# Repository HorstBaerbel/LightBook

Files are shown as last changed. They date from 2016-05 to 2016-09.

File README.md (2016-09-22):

This repository contains two similar projects: LightBook and GIFBook:  

LightBook
========
LightBook is a project that uses an ESP8266-201 module, a SD card and a WS2812 RGB LED strip (arranged as a 8*8 array) as a WiFi-enabled interactive canvas. The ESP8266 WiFi access point serves a minimalistic web page that can be used to "paint" on the LED display. The whole electronics are packaged in an old book to be put into a bookshelf.  
The code is written for the ESP8266 Arduino IDE and uses FastLED for driving the LED strip. WebSockets are used to exchange binary messages between JavaScript and the ESP module.  
The [Fritzing](http://fritzing.org/) circuit layout can be found in [LightBook_SD.fzz](LightBook_SD.fzz) and the necessary Arduino source code in [LightBook/LightBook.ino](LightBook/LightBook.ino).  
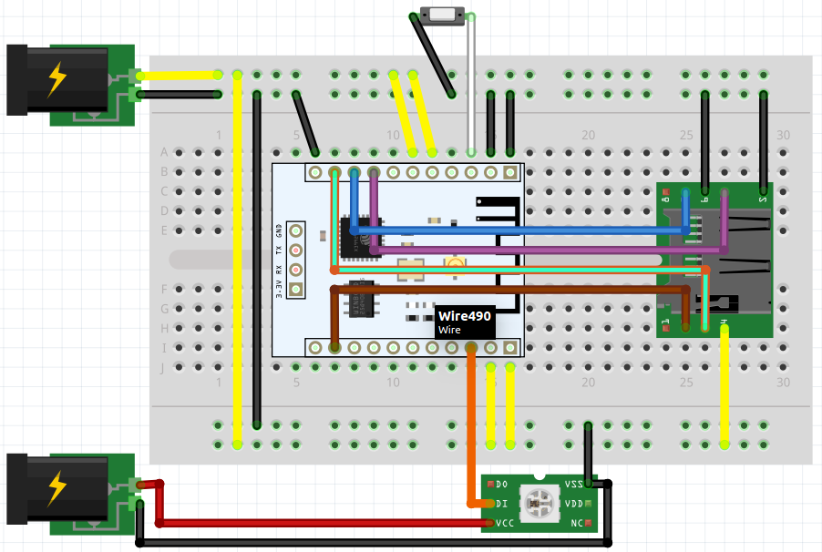
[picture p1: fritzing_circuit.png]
Fritzing circuit layout
  
You need 3.3V for the ESP8266 and 5V for the LED strip (thus the two power connectors). I generated the 3.3V with a step-down converter from the 5V line.  
Note that theres NO resistor in the WS2812s data line! The usual recommendation is to insert a ~220&#8486; resistor into the data line to prevent strips from dying, but for me this caused flickering issues due to the 3.3V signals from the ESP and does not seem to be necessary...  
Also note that only GPIOs 2 (TX1), 4 (SDA), 5 (SCL), 12 (MISO), 13 (MOSI), 14 (SCK) can be used for LED strips. GPIOs 6-11 are needed for reading/writing the attached flash chip. In theory GPIO 0, 15, 16 could work, but 0 is needed for flashing, 15 needs to be connected to GND and 16 is connected to Reset to wake the ESP from deep sleep mode. Read more about those pins here: http://www.instructables.com/id/ESP8266-Using-GPIO0-GPIO2-as-inputs/  
This circuit uses GPIO 2 and 12-14 for the SD card interface and GPIO 4 for the WS2812 strip. This leaves you with only GPIO 5 (SCL) left free for other connections...  
Some general ESP8266 GPIO info is here: http://www.esp8266.com/wiki/doku.php?id=esp8266_gpio_pin_allocations and a ESP-201 pinout is here: http://adlerweb.deviantart.com/art/ESP8266-ESP-201-Module-Pinout-Diagram-Cheat-Sheet-575951137  
The web page served look something like this and allows for simple pixel-painting on the display:  
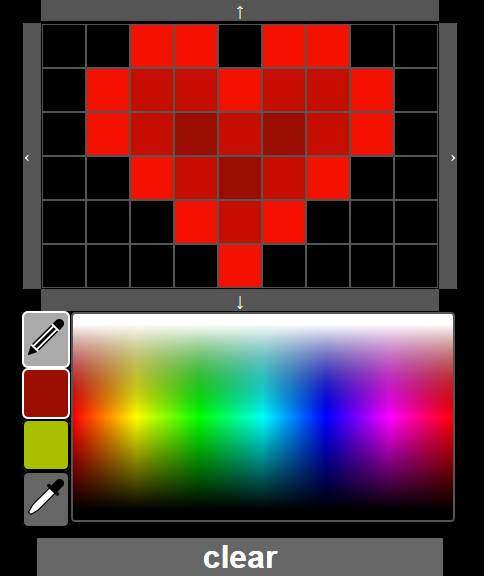
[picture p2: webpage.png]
LightBook web page served
  

GIFBook
========
GIFBook is a project that uses an ESP8266-201 module, a SD card and a WS2812 RGB LED strip (arranged as a 8*8 array) as a WiFi-enabled GIF player. You can toggle the GIF being played using a button.  
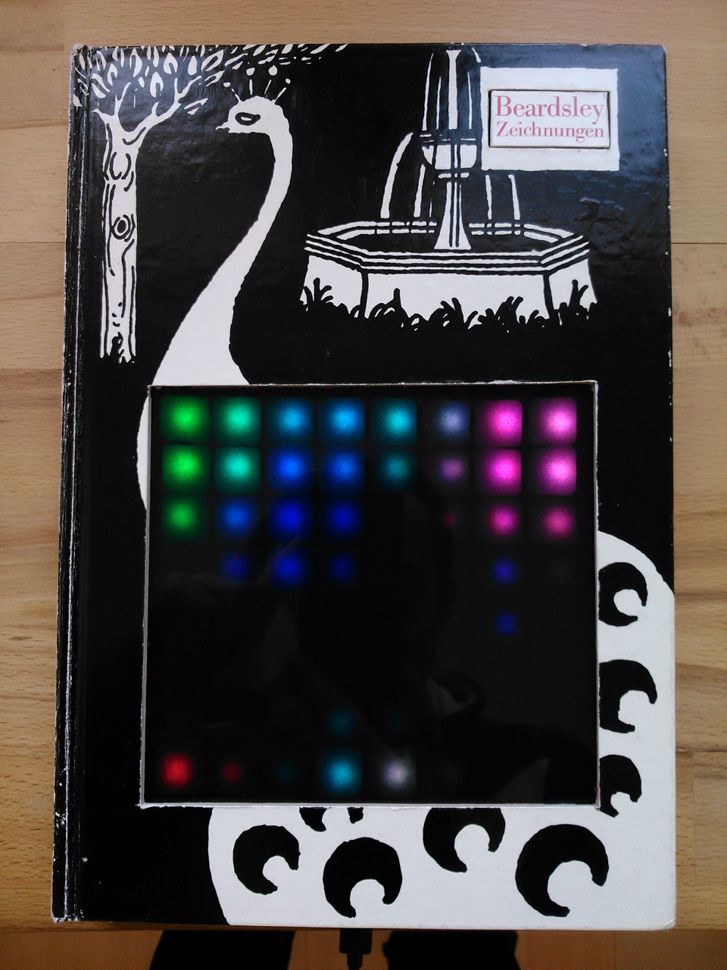
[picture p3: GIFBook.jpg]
GIFBook front
  
The code is written for the ESP8266 Arduino IDE and uses FastLED for driving the LED strip. WebSockets are used to exchange binary messages between JavaScript and the ESP module.  
The [Fritzing](http://fritzing.org/) circuit layout can be found in [LightBook_SD.fzz](LightBook_SD.fzz) and the necessary Arduino source code in [GIFBook/GIFBook.ino](GIFBook/GIFBook.ino).  
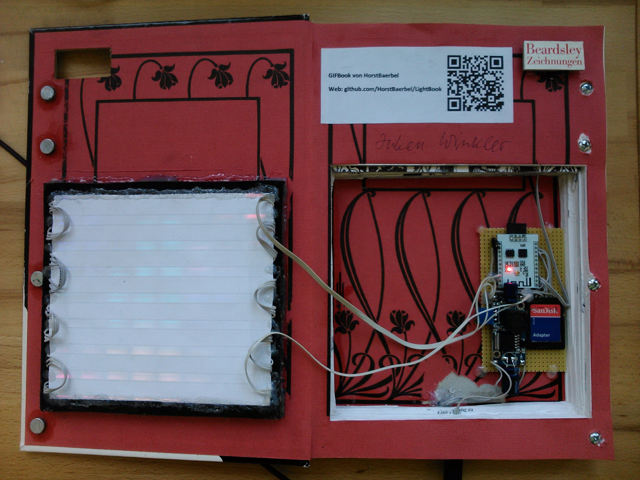
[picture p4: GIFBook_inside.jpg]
GIFBook inside
  
GIFbook plays 8x8 (and ONLY 8x8) GIFs from the /gifs folder on the SD card. It start with the first GIF (which is btw the GIF file copied to SD card first) and you can skip to the next GIF by short-pressing the button connnected to GPIO5.  

License
========
[BSD-2-Clause](http://opensource.org/licenses/BSD-2-Clause), see [LICENSE.md](LICENSE.md).  
AnimatedGIFs uses the [MIT license](https://opensource.org/licenses/MIT), see [LICENSE.txt](AnimatedGIFs/LICENSE.txt).  
I hope those are compatible...

Compiling
========
Make sure you have a recent Arduino IDE version (1.6.9+) and [support for the ESP8266](https://github.com/esp8266/Arduino). You may also need the most recent [FastLED](https://github.com/FastLED/FastLED) version. The content of the data folder should go to your FAT32-formatted SD card.  
To compile GIFBook you additionally need the wonderful [AnimatedGIFs](https://github.com/pixelmatix/AnimatedGIFs) project by [pixelmatix](https://github.com/pixelmatix) that I cloned into the AnimatedGIFs directory as a submodule. Copy the whole AnimatedGIFs folder to your Arduino library directory.

Usage
========
For LightBook, power up the circuit, connect to the AP, browse to [http://lightbook](http://lightbook) and go paint something nice :)  
For GIFBook, just power it on and push the button to show the next GIF.

I found a bug or have a suggestion
========
The best way to report a bug or suggest something is to post an issue on GitHub. Try to make it simple, but descriptive and add ALL the information needed to REPRODUCE the bug. **"Does not work" is not enough!** If you can not compile, please state your system, compiler version, etc! You can also contact me via email if you want to.

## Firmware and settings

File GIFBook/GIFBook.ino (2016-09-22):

// GIFBook sketch
// Version: v1, 21.07.2016
// Author: Bim Overbohm (bim.overbohm@googlemail.com)

// define this to have debug messages printed to the serial port
//#define OUTPUT_TO_SERIAL
#ifdef OUTPUT_TO_SERIAL
    #define DEBUG_OUTPUT(x) x
#else
    #define DEBUG_OUTPUT(x)
#endif

//#define FASTLED_ALLOW_INTERRUPTS 0 // define this if you have issues with flickering
#define FASTLED_ESP8266_RAW_PIN_ORDER // to use regular ESP GPIO numbers like GPIO13
#include "FastLED.h"

#define LED_DATA_PIN 4
//#define LED_CLOCK_PIN 5
#define LEDS_WIDTH 8
#define LEDS_HEIGHT 8
#define NUM_LEDS LEDS_WIDTH * LEDS_HEIGHT
CRGB leds[NUM_LEDS];
int16_t ledIndex[LEDS_HEIGHT][LEDS_WIDTH];
bool colorChanged = false;

//-----------------------------------------------------------------------------

#include <SPI.h>
#include <SD.h>
// set up variables using the SD utility library functions:
#define SD_CARD_CS_PIN 2
bool sdCardAvailable = false;

//-----------------------------------------------------------------------------

#include <ESP8266WiFi.h>
#include <ESP8266WebServer.h>
#include <DNSServer.h>
#include <WebSocketsServer.h>

const char * AP_SSID = "LightBook";
// const char * AP_PASSWORD = "87654321";
IPAddress AP_IP(192, 168, 1, 1);

const uint8_t DNS_PORT = 53;
DNSServer dnsServer;

WebSocketsServer webSocket = WebSocketsServer(81);
const uint8_t webSocketResponseOk[] = { 1 };
const uint8_t webSocketResponseNOk[] = { 0 };

const uint8_t MESSAGE_GIF_SELECT = 'g';

ESP8266WebServer webServer(80);
const String gifDirectory = "/gifs";
File uploadFile;

//-----------------------------------------------------------------------------

#define BUTTON_PIN 5 // button to cycle GIFs

//button press durations in ms
#define RELEASE_DURATION 50
#define SHORT_PRESS_DURATION 50
#define LONG_PRESS_DURATION 4000

//button state variables.
uint8_t lastButtonPin = LOW;
int32_t lastButtonStart = 0;
uint8_t currentButtonState = 0; //0 = released, 1 = short pressed, 2 = long pressed
bool buttonWasPressedShort = false;
bool buttonWasPressedLong = false;

//-----------------------------------------------------------------------------

#include "GifDecoder.h"
GifDecoder<LEDS_WIDTH, LEDS_HEIGHT, 10> gifDecoder;
File gifFile;
String gifFileName = "";

//-----------------------------------------------------------------------------

void webSocketSendServerMessage(uint8_t num, const uint8_t * payload, size_t length)
{
    uint8_t * message = new uint8_t[sizeof(uint32_t) + length];
    *((uint32_t *)message) = 0;
    memcpy(&message[sizeof(uint32_t)], payload, length);
    webSocket.sendBIN(num, message, sizeof(uint32_t) + length);
    delete message;
}

void webSocketSendResponse(uint8_t num, uint32_t messageId, bool ok)
{
    uint8_t response[5];
    *((uint32_t *)response) = messageId;
    response[4] = (uint8_t)ok;
    webSocket.sendBIN(num, response, sizeof(response));
}

uint32_t webSocketMessageIdFromData(const uint8_t * payload, size_t length)
{
    if (payload != nullptr && length >= 4) {
        uint32_t id = *((const uint32_t *)payload);
        return id;
    }
    return 0;
}

void webSocketHandleMessage(uint8_t num, WStype_t type, uint8_t * payload, size_t length)
{
    DEBUG_OUTPUT(Serial.print("Message from client #");) DEBUG_OUTPUT(Serial.println(num);)
    //for (int i = 0; i < length; ++i) { DEBUG_OUTPUT(Serial.print(payload[i]);) DEBUG_OUTPUT(Serial.print(" ");) } DEBUG_OUTPUT(Serial.println();)
    // check the type of event
    switch(type)
    {
    case WStype_DISCONNECTED:
        DEBUG_OUTPUT(Serial.println("Websocket disonnected");)
        break;
    case WStype_CONNECTED:
        DEBUG_OUTPUT(Serial.println("Websocket connected");)
        break;
    case WStype_TEXT:
        // unknown message, send negative response
        DEBUG_OUTPUT(Serial.println("Unknown text message received");)
        webSocketSendResponse(num, 0, false);
        //webSocket.sendTXT(num, payload, length); // send to client
        //webSocket.broadcastTXT(payload, length); // send to all clients
        break;
    case WStype_BIN:
        // check if the packet contained data
        if (payload != nullptr && length > 4)
        {
            const uint32_t messageId = webSocketMessageIdFromData(payload, length);
            const char messageType = (char)payload[4];
            const uint8_t * messageData = (const uint8_t *)&payload[5];
            DEBUG_OUTPUT(Serial.print("Binary message id: ");) DEBUG_OUTPUT(Serial.print(messageId);) DEBUG_OUTPUT(Serial.print(" type: ");) DEBUG_OUTPUT(Serial.print(messageType);) DEBUG_OUTPUT(Serial.println(" received");)
            // check if this is a color for a specific led. format is ID, 'g', file name.gif
            if (messageType == MESSAGE_GIF_SELECT && length >= 6)
            {
                webSocketSendResponse(num, messageId, true);
            }
            else
            {
                // unknown message, send negative response
                webSocketSendResponse(num, messageId, false);
            }
        }
        break;
    }
}

//-----------------------------------------------------------------------------

void returnOk()
{
  webServer.send(200, "text/plain", "");
}

void returnFail(String msg)
{
  webServer.send(500, "text/plain", msg + "\r\n");
}

void returnDoesNotExist(String msg)
{
  webServer.send(404, "text/plain", msg + "\r\n");
}

String getContentType(String filename){
    if (webServer.hasArg("download")) return "application/octet-stream";
    else if (filename.endsWith(".htm")) return "text/html";
    else if (filename.endsWith(".html")) return "text/html";
    else if (filename.endsWith(".css")) return "text/css";
    else if (filename.endsWith(".js")) return "application/javascript";
    else if (filename.endsWith(".png")) return "image/png";
    else if (filename.endsWith(".gif")) return "image/gif";
    else if (filename.endsWith(".jpg")) return "image/jpeg";
    else if (filename.endsWith(".ico")) return "image/x-icon";
    else if (filename.endsWith(".xml")) return "text/xml";
    else if (filename.endsWith(".pdf")) return "application/x-pdf";
    else if (filename.endsWith(".zip")) return "application/x-zip";
    else if (filename.endsWith(".gz")) return "application/x-gzip";
    return "text/plain";
}

bool loadFileFromSDCard(String path)
{
    if (!sdCardAvailable) {
        return false;
    }
    String dataType = getContentType(path);
    // try opening file
    DEBUG_OUTPUT(Serial.print("Opening: ");) DEBUG_OUTPUT(Serial.println(path);)
    File dataFile = SD.open(path.c_str());
    // check if directory and add index.htm to it
    if (dataFile.isDirectory()) {
        path += "/index.htm";
        dataType = "text/html";
        dataFile = SD.open(path.c_str());
    }
    // check if opened
    if (!dataFile) {
        DEBUG_OUTPUT(Serial.println("Failed to open file.");)
        return false;
    }
    // send data to client
    //if (server.hasArg("download")) dataType = "application/octet-stream";
    if (webServer.streamFile(dataFile, dataType) != dataFile.size()) {
        DEBUG_OUTPUT(Serial.println("Sent less data than expected!");)
    }
    dataFile.close();
    return true;
}

void handleClientRequest()
{
    DEBUG_OUTPUT(Serial.print("Page request: ");) DEBUG_OUTPUT(Serial.println(webServer.uri());)
    if (!loadFileFromSDCard(webServer.uri())) {
        returnDoesNotExist("Page " + webServer.uri() + " does not exist or no SD card inserted!");
    }
    returnOk();
}

void handleFileUpload()
{
    // check URI for image directory
    if (webServer.uri() != gifDirectory) {
        returnFail("Bad path");
        return;
    }
    // check if the upload path contains the image directory
    HTTPUpload & upload = webServer.upload();
    if (!upload.filename.startsWith(gifDirectory + "/")) {
        returnFail("Can only write in " + gifDirectory);
        return;
    }
    // ok check what phase of the upload we're in
    if (upload.status == UPLOAD_FILE_START) {
        // if the file exists, delete it first
        if (SD.exists((char *)upload.filename.c_str())) {
            SD.remove((char *)upload.filename.c_str());
        }
        // open file for writing
        uploadFile = SD.open(upload.filename.c_str(), FILE_WRITE);
        DEBUG_OUTPUT(Serial.print("Upload: START, filename: ");) DEBUG_OUTPUT(Serial.println(upload.filename);)
    }
    else if (upload.status == UPLOAD_FILE_WRITE) {
        // if the file is open, write data to it
        if (uploadFile) {
            uploadFile.write(upload.buf, upload.currentSize);
        }
        DEBUG_OUTPUT(Serial.print("Upload: WRITE, Bytes: ");) DEBUG_OUTPUT(Serial.println(upload.currentSize);)
    }
    else if (upload.status == UPLOAD_FILE_END) {
        // if the file is open, close it
        if (uploadFile) {
            uploadFile.close();
        }
        DEBUG_OUTPUT(Serial.print("Upload: END, Size: ");) DEBUG_OUTPUT(Serial.println(upload.totalSize);)
    }
}

void handleDelete()
{
    /*if (webServer.args() == 0) {
        returnFail("Bad args");
        return;
    }
    String path = webServer.arg(0);
    if (path == "/") {
        returnFail("Bad path");
        return;
    }
    if (!SD.exists((char *)path.c_str())) {
        returnFail(path + " does not exist");
        return;
    }
    if (!path.startsWith(gifDirectory + "/")) {
        returnFail("Can only write in " + gifDirectory);
        return;
    }
    File file = SD.open((char *)path.c_str());
    if (!file.isDirectory()) {
        file.close();
        returnFail("Can't delete directories");
        return;
    }
    file.close();
    SD.remove((char *)path.c_str());*/
    returnOk();
}

//-----------------------------------------------------------------------------

void buildLedIndices()
{
    for (int y = 0; y < LEDS_HEIGHT; y++) {
        int index = y * LEDS_WIDTH;
        for (int x = 0; x < LEDS_WIDTH; x++) {
            // if y is odd, we need to turn x around
            ledIndex[y][x] = index + ((y & 1) ? (LEDS_WIDTH - 1 - x) : x);
        }
    }
}

void setColor(CRGB incol)
{
    for (int i = 0; i < NUM_LEDS; i++)
    {
        leds[i] = incol;
    }
}

void screenClearCallback(void) { const CRGB black = {0, 0, 0}; setColor(black); }

void updateScreenCallback(void) { FastLED.show(); }

void drawPixelCallback(int16_t x, int16_t y, uint8_t r, uint8_t g, uint8_t b) { const CRGB col = {r, g, b}; leds[ledIndex[y][x]] = col; }

//-----------------------------------------------------------------------------

bool showNextGIF()
{
    DEBUG_OUTPUT(Serial.println("Opening GIF directory");)
    // try opening GIF directory
    File directory = SD.open(gifDirectory);
    if (!directory) {
        return false;
    }
    // if we are not currently showing a GIF file, show the first one
    if (!gifFile || gifFileName == "") {
        File file = directory.openNextFile();
        String firstFileName = file.name();
        file.close();
        directory.close();
        return showGIF(gifDirectory + "/" + firstFileName);
    }
    DEBUG_OUTPUT(Serial.println("Opened GIF directory");)
    // look for the current GIF in the files
    uint16_t currentIndex = 0;
    uint16_t fileCount = 0;
    File file = directory.openNextFile();
    while (file) {
        String fileName = file.name();
        fileName.toLowerCase();
        DEBUG_OUTPUT(Serial.println("Current file: " + fileName);)
        // check if the file is a gif
        if (!fileName.startsWith(".") && fileName.endsWith(".gif")) {
            // check if it is the current file
            if (gifFileName.endsWith(fileName)) {
                currentIndex = fileCount;
                DEBUG_OUTPUT(Serial.println("Current GIF file " + fileName + " found");)
            }
        }
        fileCount++;
        file.close();
        file = directory.openNextFile();
    }
    file.close();
    // now we have found the file, or the index is still zero. we don't care and increase it. this is the next file we show
    const uint16_t newIndex = (currentIndex + 1) % fileCount;
    currentIndex = 0;
    String newFileName = "";
    directory.rewindDirectory();
    file = directory.openNextFile();
    while (file) {
        String fileName = file.name();
        fileName.toLowerCase();
        // check if the file is a gif
        if (!fileName.startsWith(".") && fileName.endsWith(".gif")) {
            // check if it is the current file
            if (newIndex == currentIndex) {
                newFileName = fileName;
                DEBUG_OUTPUT(Serial.println("New GIF file " + newFileName + " found");)
            }
        }
        currentIndex++;
        file.close();
        file = directory.openNextFile();
    }
    file.close();
    directory.close();
    // now open file if we've found one
    if (newFileName != "") {
        return showGIF(gifDirectory + "/" + newFileName);
    }
    return false;
}

bool showGIF(String fileName)
{
    if (gifFile) {
        //gifDecoder.stopDecoding();
        gifFile.close();
        gifFileName = "";
    }
    // attempt to open the file for reading
    gifFile = SD.open(fileName);
    if (gifFile) {
        gifFileName = fileName;
        gifDecoder.startDecoding();
        DEBUG_OUTPUT(Serial.println("Opened GIF file " + fileName);)
        return true;
    }
    DEBUG_OUTPUT(Serial.println("Failed to open GIF file " + fileName);)
    return false;
}

void handleGIF()
{
    if (gifFile) {
        gifDecoder.decodeFrame();
    }
}

bool fileSeekCallback(unsigned long position) { return gifFile.seek(position); }

unsigned long filePositionCallback(void) { return gifFile.position(); }

int fileReadCallback(void) { return gifFile.read(); }

int fileReadBlockCallback(void * buffer, int numberOfBytes) { return gifFile.read(buffer, numberOfBytes); }

//-----------------------------------------------------------------------------

void buttonReadState()
{
    //the state must be button signal high, hold high SHORT_PRESS_DURATION, signal low, hold low RELEASE_DURATION -> valid short press
    //the state must be button signal high, hold high LONG_PRESS_DURATION, signal low, hold low RELEASE_DURATION -> valid long press
    //check what state the pin is in
    const byte state = digitalRead(BUTTON_PIN);
    //check if the state is the same as before
    if (state == lastButtonPin) {
      //state is the same. check what it is
      if (state == LOW) {
        //button still pressed
        if (currentButtonState == 0) {
          //button was released before. check if enough time has passed to get a short/long press
          if ((millis() - lastButtonStart) >= SHORT_PRESS_DURATION) {
            DEBUG_OUTPUT(Serial.print("Short press");)
            currentButtonState = 1;
          }
        }
        if (currentButtonState == 1) {
          //button was pressed before. check if enough time has passed to get a long press
          if ((millis() - lastButtonStart) >= LONG_PRESS_DURATION) {
            DEBUG_OUTPUT(Serial.print("Long press");)
            currentButtonState = 2;
          }
        }
      }
      else {
        //button still unpressed
        if (currentButtonState == 1) {
          //button was short pressed and released. was the release long enough
          if ((millis() - lastButtonStart) >= RELEASE_DURATION) {
            DEBUG_OUTPUT(Serial.print("Short release");)
            buttonWasPressedShort = true;
            buttonWasPressedLong = false;
            currentButtonState = 0;
          }
        }
        else if (currentButtonState == 2) {
          //button was pressed and released. was the release long enough
          if ((millis() - lastButtonStart) >= RELEASE_DURATION) {
            DEBUG_OUTPUT(Serial.print("Long release");)
            buttonWasPressedShort = false;
            buttonWasPressedLong = true;
            currentButtonState = 0;
          }
        }
      }
    }
    else {
      //state changed. store time
      lastButtonStart = millis();
      lastButtonPin = state;
      DEBUG_OUTPUT(Serial.print("Button state = ");) DEBUG_OUTPUT(Serial.println(state);)
    }
}

void buttonDoCommands()
{
    if (buttonWasPressedLong) {
        // what?
        buttonWasPressedLong = false;
        buttonWasPressedShort = false;
    }
    else if (buttonWasPressedShort) {
        showNextGIF();
        buttonWasPressedLong = false;
        buttonWasPressedShort = false;
    }
}

//-----------------------------------------------------------------------------

void setup()
{
    // set up GPIO5 as an input with a pull-up resistor
    pinMode(BUTTON_PIN, INPUT_PULLUP);
    // set up serial port for debug output
    DEBUG_OUTPUT(Serial.begin(115200);)
    //while (!DEBUG_OUTPUT) { delay(500); }
    DEBUG_OUTPUT(Serial.println("LightBook starting...");)
    // initialize SD card
    if (SD.begin(SD_CARD_CS_PIN)) {
        DEBUG_OUTPUT(Serial.println("Initialized SD card");)
        sdCardAvailable = true;
    }
    else {
        DEBUG_OUTPUT(Serial.println("Failed to initialize SD card!");)
    }
    // set up WiFi access point
    WiFi.mode(WIFI_AP);
    WiFi.softAPConfig(AP_IP, AP_IP, IPAddress(255, 255, 255, 0));
    WiFi.softAP(AP_SSID);
    // set up DNS server as a captive portal. we reply with the AP_IP for all DNS requests 
    dnsServer.setErrorReplyCode(DNSReplyCode::NoError);
    dnsServer.start(DNS_PORT, "*", AP_IP);
    // set up web server
    webServer.on("/", handleClientRequest);
    webServer.onNotFound(handleClientRequest);
    //webServer.on("/gifs", HTTP_POST, [](){ returnOk(); }, handleFileUpload);
    //webServer.on("/gifs", HTTP_DELETE, handleDelete);
    webServer.begin();
    // set up websockets
    webSocket.begin();
    webSocket.onEvent(webSocketHandleMessage);
    // set up LED strip output
    FastLED.addLeds<WS2812, LED_DATA_PIN, GRB>(leds, NUM_LEDS);
    //FastLED.setCorrection(TypicalLEDStrip); //makes the colors look funny...
    FastLED.setTemperature(Tungsten40W); // gives me colors closer to what I see on my screen...
    FastLED.setDither(DISABLE_DITHER);
    FastLED.setBrightness(128);
    // build indices for LED indexing
    buildLedIndices();
    // show initial rgb "flash"
    setColor(CRGB(255, 0, 0)); FastLED.show(); delay(250);
    setColor(CRGB(0, 255, 0)); FastLED.show(); delay(250);
    setColor(CRGB(0, 0, 255)); FastLED.show(); delay(250);
    setColor(CRGB(0, 0, 0)); FastLED.show();
    // set up the GIF gifDecoder
    gifDecoder.setScreenClearCallback(screenClearCallback);
    gifDecoder.setUpdateScreenCallback(updateScreenCallback);
    gifDecoder.setDrawPixelCallback(drawPixelCallback);
    gifDecoder.setFileSeekCallback(fileSeekCallback);
    gifDecoder.setFilePositionCallback(filePositionCallback);
    gifDecoder.setFileReadCallback(fileReadCallback);
    gifDecoder.setFileReadBlockCallback(fileReadBlockCallback);
    // start displaying the first GIF
    showNextGIF();
}

//-----------------------------------------------------------------------------

void loop()
{
    // handle DNS requests
    dnsServer.processNextRequest();
    // handle http request from clients
    webServer.handleClient();
    // handle websocket requests
    webSocket.loop();
    // handle button presses
    buttonReadState();
    buttonDoCommands();
    // handle GIF frames or change images
    handleGIF();
}

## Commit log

2016-06-04 Point out to flickering issue in README and add link to GitHub
    [LightBook.ino]
2016-07-22 Add forked AnimatedGIFs and update README etc
    [LightBook_SD.fzz]
